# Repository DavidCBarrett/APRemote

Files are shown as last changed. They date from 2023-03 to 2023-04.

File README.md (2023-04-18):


# APRemote
Web based autopilot control using ESP32 and Seatalk1

Seatalk 1 is a 9bit protocol with 9th bit being set to indicate a command byte. Decoding is done using the ESPSoftwareSerial library.
INitialise the software port as 8 bit and Space parity. Test the parity bit before reading data if it is set then the byte
being read is a command bit.

ESP32 sketch on Arduino IDE. Reads and writes Seatalk1 to display data and send AP commannds to control X10 smart pilot.

Seatalk processing in Core 0 on ESP32.

HTML/CSS files for web page uploaded via SPIFFS.

More details to follow.

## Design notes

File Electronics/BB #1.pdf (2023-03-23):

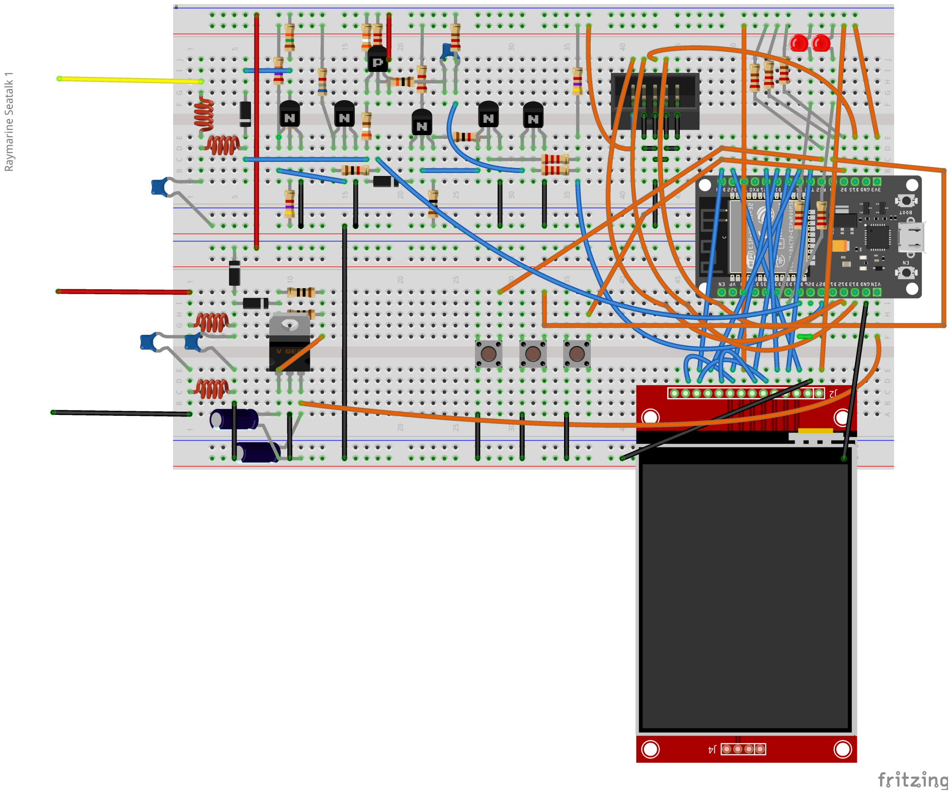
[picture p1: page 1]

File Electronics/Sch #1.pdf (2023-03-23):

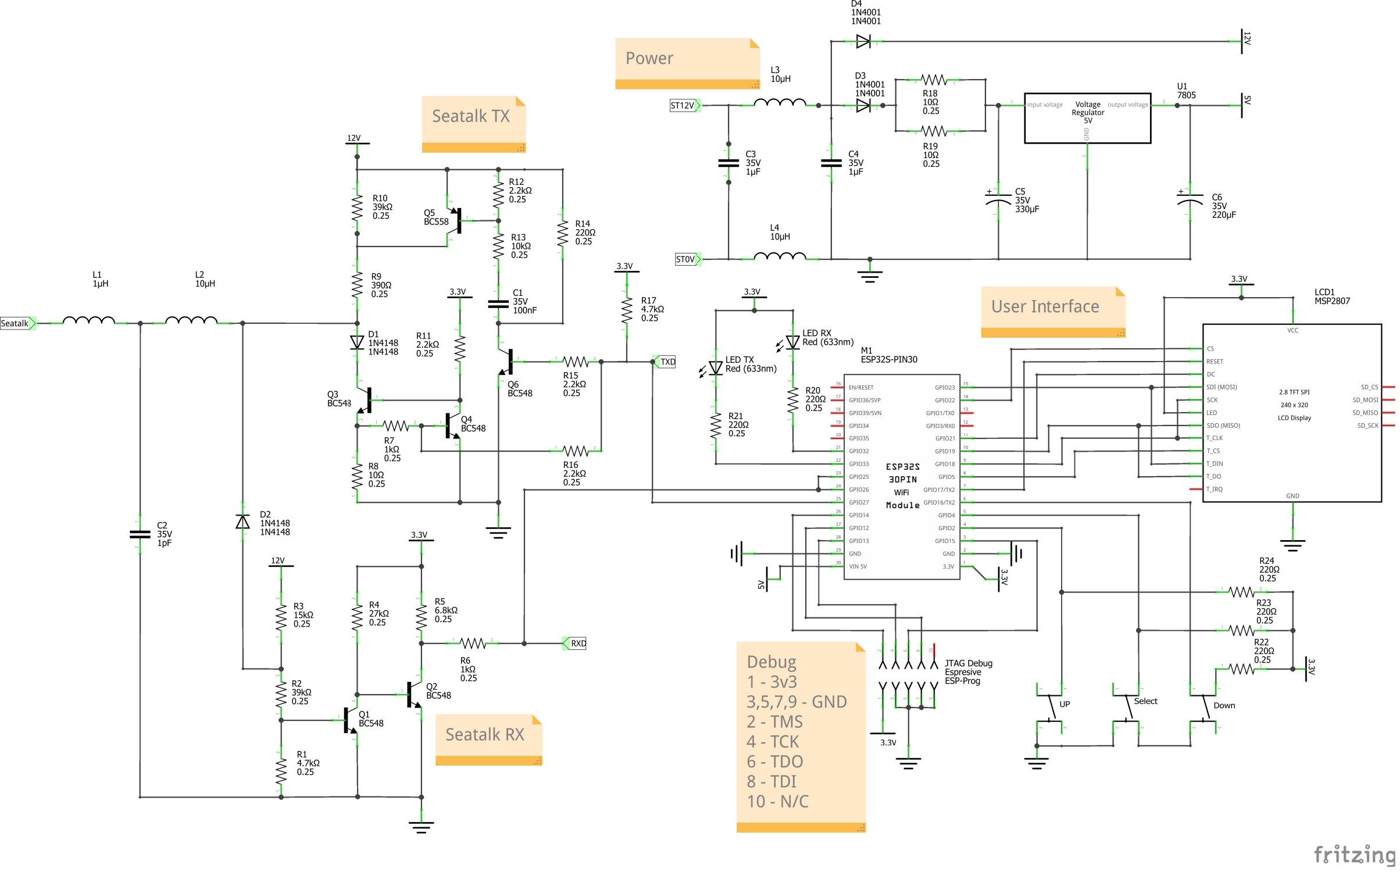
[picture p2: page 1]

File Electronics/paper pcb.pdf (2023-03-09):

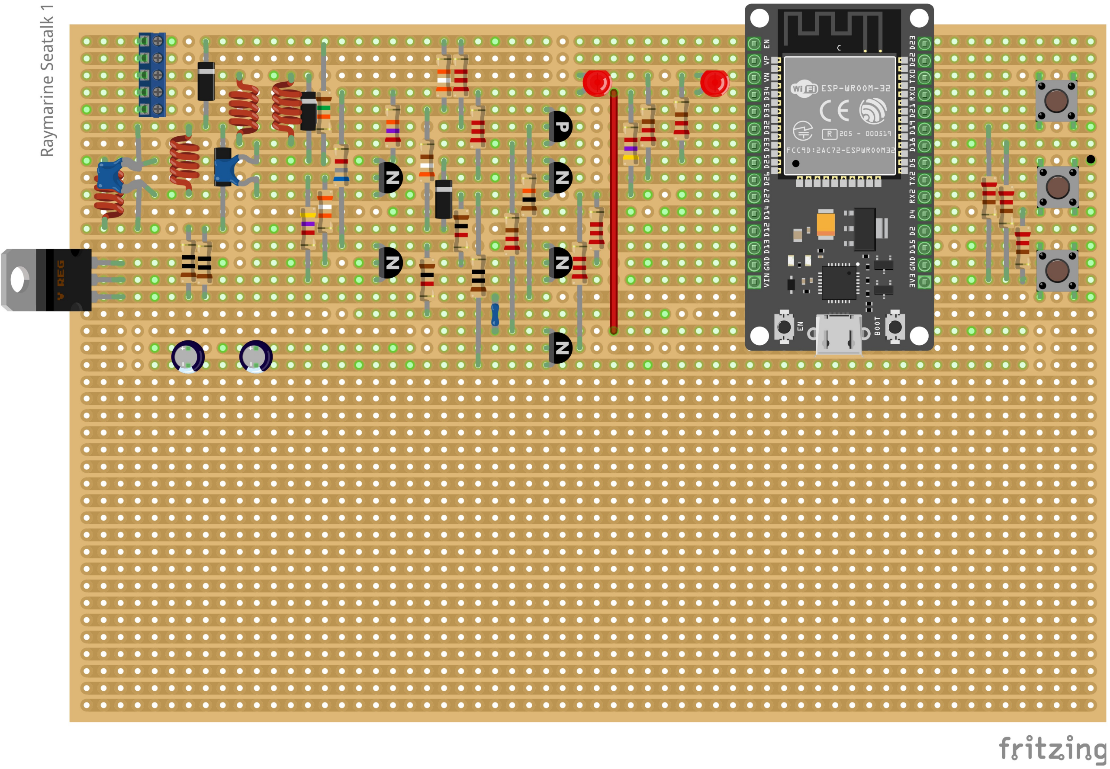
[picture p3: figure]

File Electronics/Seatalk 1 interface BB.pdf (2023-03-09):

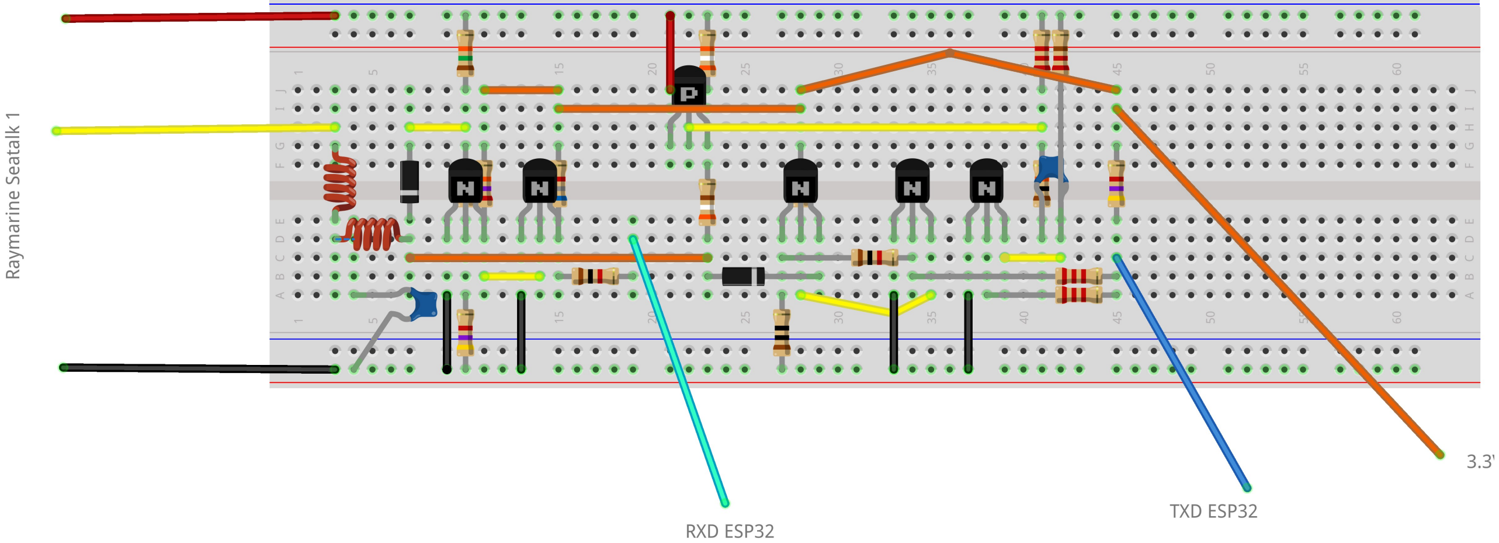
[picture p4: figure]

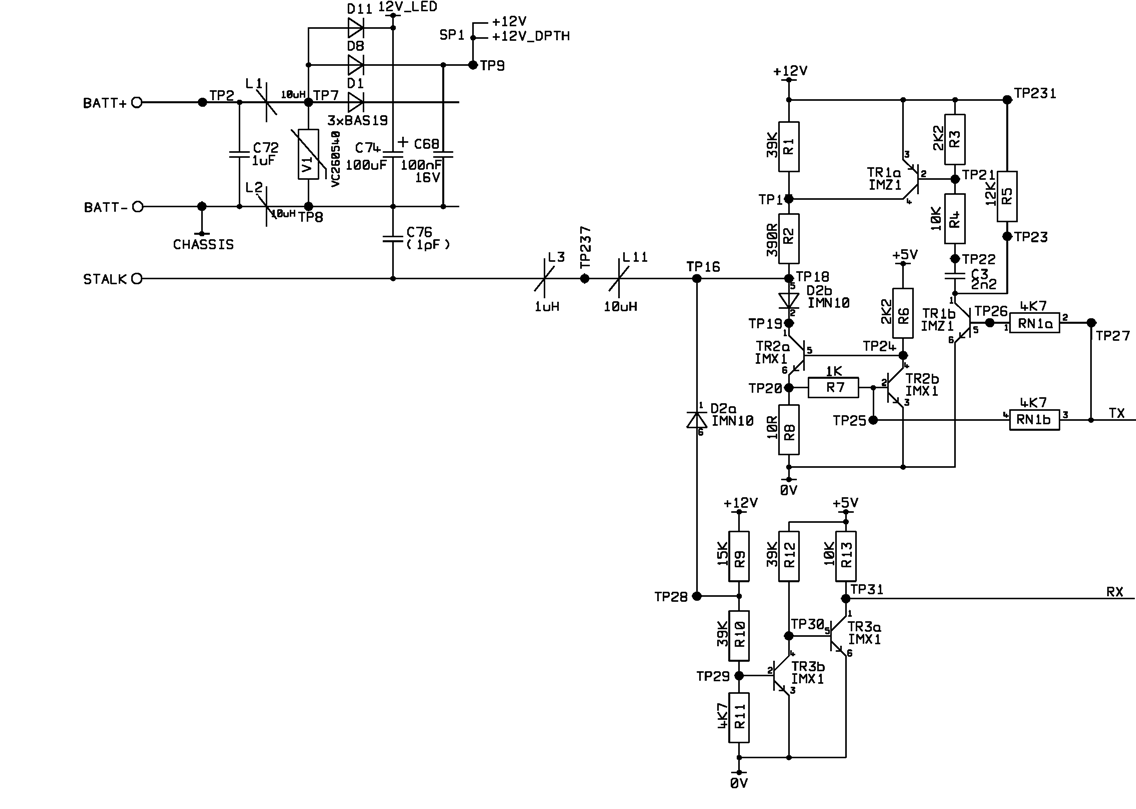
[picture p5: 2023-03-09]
Electronics/ST-IO.png

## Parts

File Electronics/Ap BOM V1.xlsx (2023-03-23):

Shopping List
Amount | MN (manufacturer number) | MPN (manufacturer part number) | Part Type | Properties
1 |  |  | Ceramic Capacitor | package 100 mil [THT, multilayer]; capacitance 100nF; voltage 35V
1 |  |  | Ceramic Capacitor | package 100 mil [THT, multilayer]; capacitance 1pF; voltage 35V
2 |  |  | Ceramic Capacitor | package 100 mil [THT, multilayer]; capacitance 1µF; voltage 35V
1 |  |  | Electrolytic Capacitor | package 100 mil [THT, electrolytic]; capacitance 330µF; voltage 35V
1 |  |  | Electrolytic Capacitor | package 100 mil [THT, electrolytic]; capacitance 220µF; voltage 35V
2 |  | 1N4148 | Rectifier Diode | package 300 mil [THT]; type Rectifier; mpn 1N4148; part # 1N4148
2 |  | 1N4001 | Rectifier Diode | package 300 mil [THT]; type Rectifier; mpn 1N4001; part # 1N4001
1 |  |  | Inductor | inductance 1µH; package 400 mil [THT]
3 |  |  | Inductor | inductance 10µH; package 400 mil [THT]
2 |  |  | Red (633nm) LED | color Red (633nm); package 3 mm [THT] Top; leg yes
1 |  |  | DOIT Esp32 DevKit v1 (30 pins long, 11 pins width) | pins 30; variant 1; part # ESP32S-PIN30
5 |  | BC548 | NPN-Transistor | package TO92 [THT]; type NPN (CBE); mpn BC548
1 |  | BC558 | PNP-Transistor | package TO92 [THT]; type PNP (CBE); mpn BC558
2 |  |  | 4.7kΩ Resistor | pin spacing 400 mil; package THT; resistance 4.7kΩ; power 0.25; bands 4; tolerance ±5%
2 |  |  | 39kΩ Resistor | pin spacing 400 mil; package THT; resistance 39kΩ; power 0.25; bands 4; tolerance ±5%
1 |  |  | 15kΩ Resistor | pin spacing 400 mil; package THT; resistance 15kΩ; power 0.25; bands 4; tolerance ±5%
1 |  |  | 27kΩ Resistor | pin spacing 400 mil; package THT; resistance 27kΩ; power 0.25; bands 4; tolerance ±5%
1 |  |  | 6.8kΩ Resistor | pin spacing 400 mil; package THT; resistance 6.8kΩ; power 0.25; bands 4; tolerance ±5%
2 |  |  | 1kΩ Resistor | pin spacing 400 mil; package THT; resistance 1kΩ; power 0.25; bands 4; tolerance ±5%
3 |  |  | 10Ω Resistor | pin spacing 400 mil; package THT; resistance 10Ω; power 0.25; bands 4; tolerance ±5%
1 |  |  | 390Ω Resistor | pin spacing 400 mil; package THT; resistance 390Ω; power 0.25; bands 4; tolerance ±5%
4 |  |  | 2.2kΩ Resistor | pin spacing 400 mil; package THT; resistance 2.2kΩ; power 0.25; bands 4; tolerance ±5%
1 |  |  | 10kΩ Resistor | pin spacing 400 mil; package THT; resistance 10kΩ; power 0.25; bands 4; tolerance ±5%
6 |  |  | 220Ω Resistor | pin spacing 400 mil; package THT; resistance 220Ω; power 0.25; bands 4; tolerance ±5%
3 |  |  | Pushbutton | package [THT]; switch status Released
1 |  | 7805 | Voltage Regulator - 5V | package TO220 [THT]; voltage 5V; mpn 7805

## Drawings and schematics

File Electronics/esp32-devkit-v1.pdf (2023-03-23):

MICRO USB | VOLTAGE REGULATOR

# BOOT & ENABLE

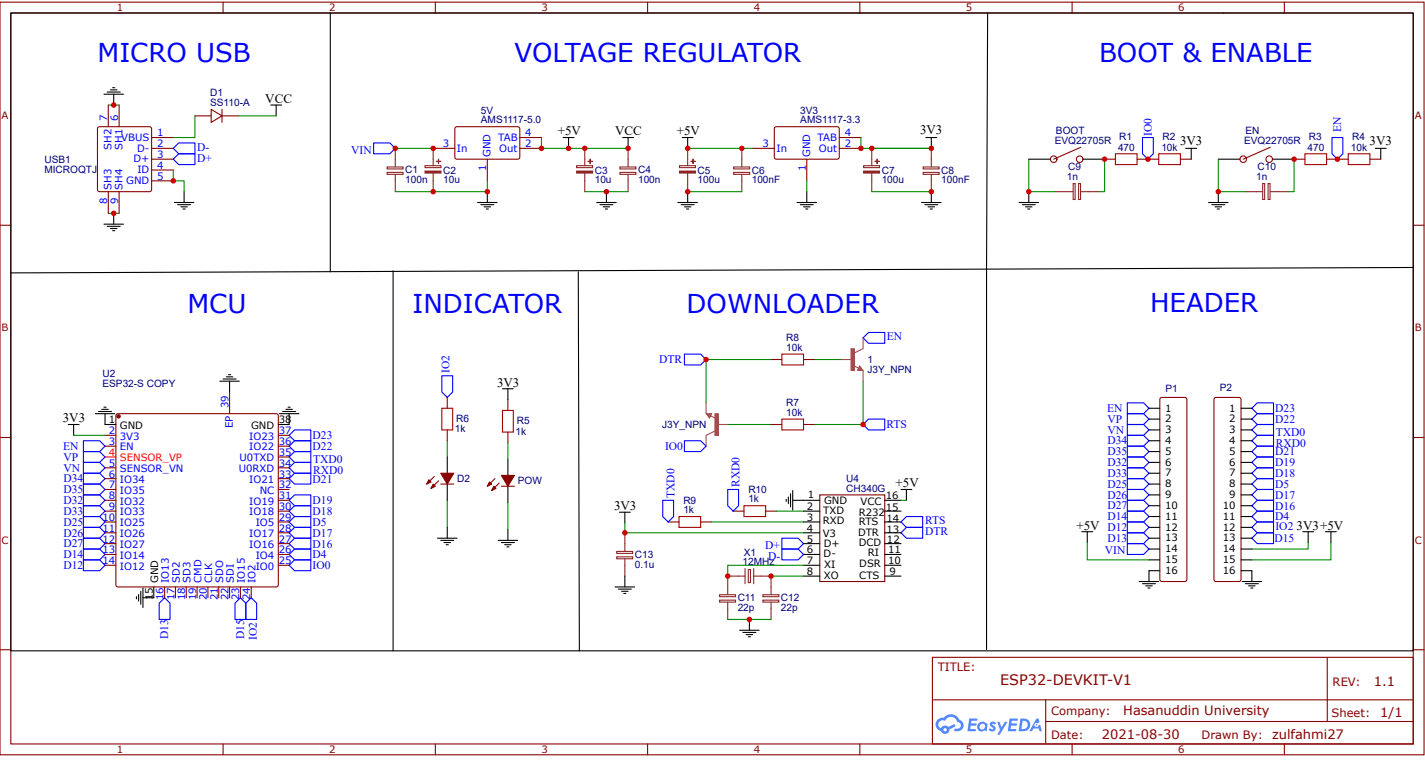
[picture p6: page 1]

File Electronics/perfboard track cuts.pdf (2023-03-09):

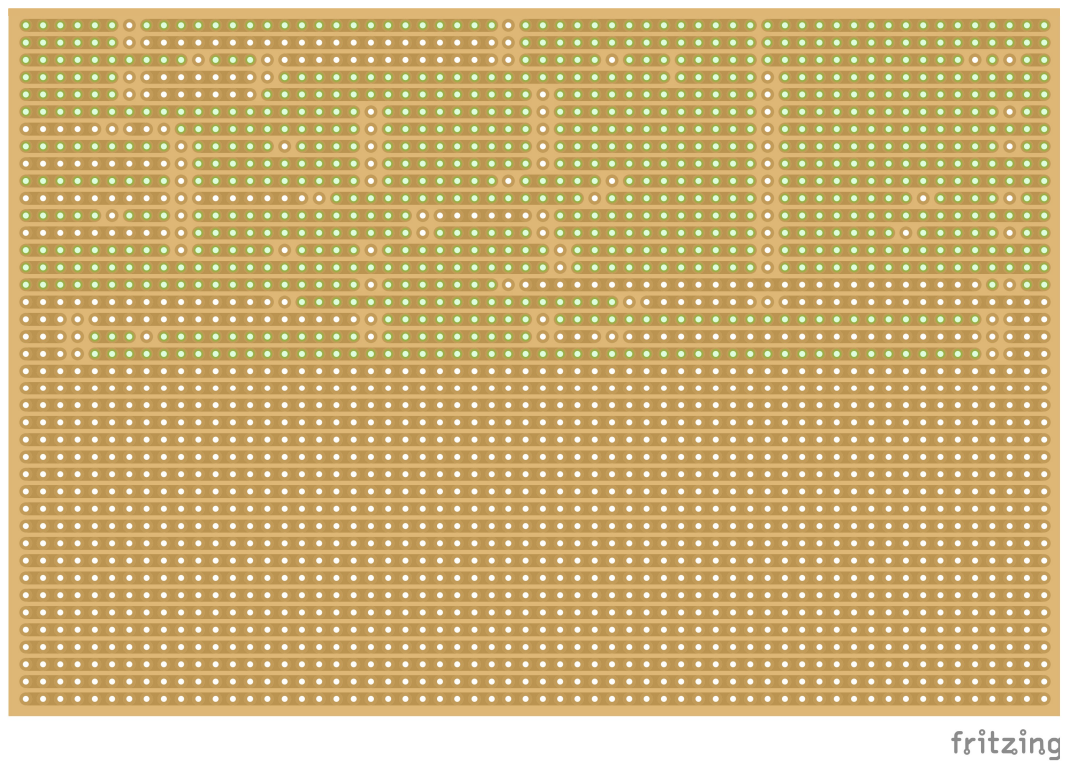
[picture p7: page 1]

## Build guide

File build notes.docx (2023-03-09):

ApRemote – a web based Raymarine SeaTalk 1 autohelm remote control

Source: https://github.com/richardJG/APRemote, Last commit, Nov 2020

Platform IO

Libraries for build:

Name & author | PlatformIO libdeps entry: | Version | Maintainer

Moving to alternative web sockets library & code in ApRemote in PlatformIO

https://m1cr0lab-esp32.github.io/remote-control-with-websocket/led-setup/

Now complies :-)

String send to client with data is:

267{"hdg":0,"cts":0,"hdgInfo":"&nbsp;","rsa":"S0","sog":0.00,"cog":0,"awa":"0S","xte":"---","aws":0.00,"vlw":0.00,"dpt":0.00,"stw":0.00,"dtw":"---","btw":"---","left":"&nbsp;","right":"&nbsp;","led0":"led_on","led1":"led_off","led2":"led_off","led3":"led_off","alm":" "}

Adding Wi-Fi Access point capability

Rui Santo’s Tutorials: https://RandomNerdTutorials.com/

ESP32 Access Point (AP) for Web Server | Random Nerd Tutorials (https://randomnerdtutorials.com/esp32-access-point-ap-web-server/)

SeaTalk 1 interface circuit.

Original (for 5V microcontroller):


Reworked for 3.3V microcontroller:

Using EasyEDA simulation mode.

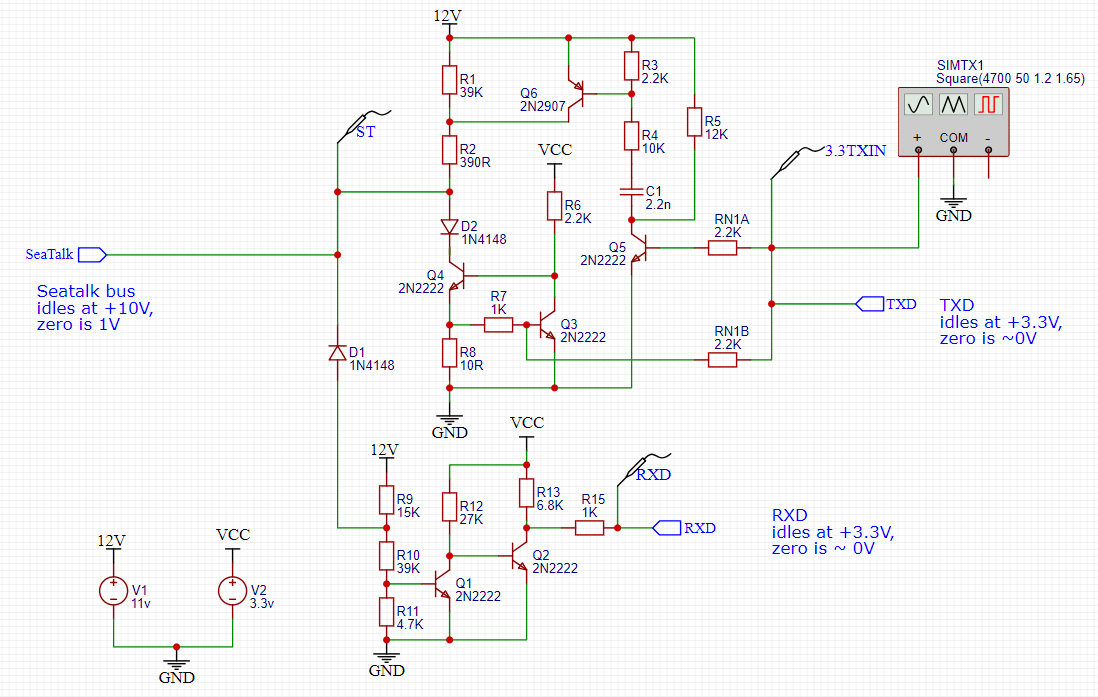
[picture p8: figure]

5V (VCC) related resistors have been scaled by 3.3/5 and nearest standard value selected.

Simulation showed circuit works with 11, 12 and 14V charge states of 12V lead acid battery.

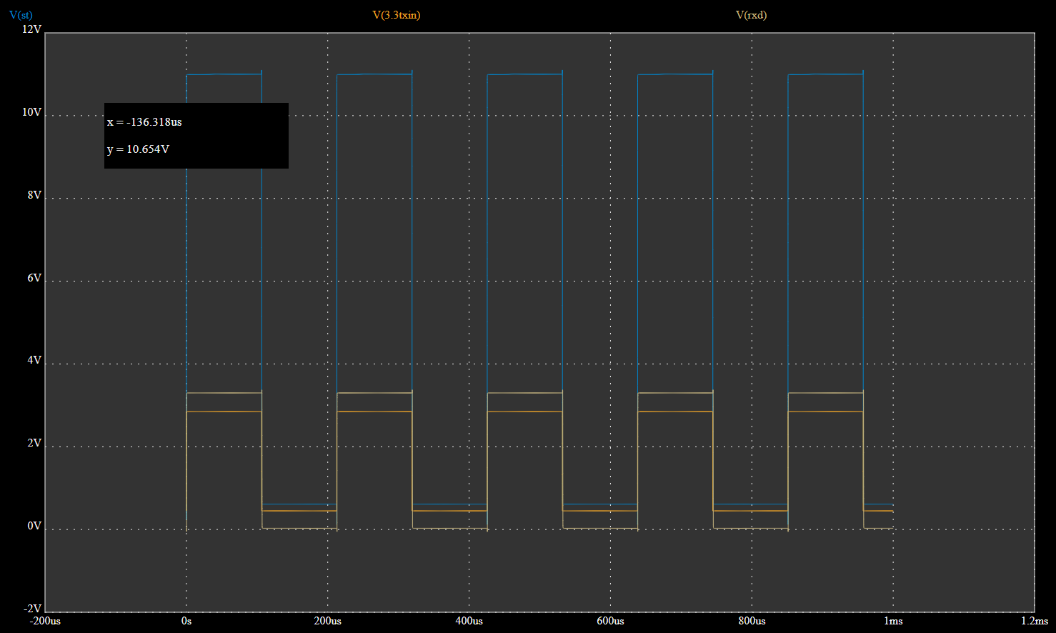
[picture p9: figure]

Prototyping the circuit

Veroboard layout tool: https://github.com/bancika/diy-layout-creator

Tutorial: https://www.youtube.com/watch?v=mzje3eHqi2E

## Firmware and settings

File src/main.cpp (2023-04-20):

//<App !Start!>
// FILE: [main.cpp]
// Created by GUIslice Builder version: [0.17.b21]
//
// GUIslice Builder Generated File
//
// For the latest guides, updates and support view:
// https://github.com/ImpulseAdventure/GUIslice
//
//<App !End!>

/*
WebServer for Raymarine Seatalk 1 based autohelm (with other boat data). 
Control your autohelm & see boat data using your phone's web browser.

Original project from https://github.com/richardJG/APRemote 

Main changes: 
1. Migrated to VS Code with PlatformIO enviornment

2. Swapped out WebSockets_Generic (which caused me lots of comple problems) for the Web Socket Server already in ESPAsyncWebServer. 
   Inpiration / info for the changes taken from the tutorial at https://m1cr0lab-esp32.github.io/remote-control-with-websocket/

3. Moved from hard coded WiFI credentials to using WiFiManager with AutoPilot Remote Access Point Web page at 192.168.4.1. 
   Connecting to the AutoPilot Remote network will bring up the web page.

4. Added buttons to ESP32. use is up/sel/down for (future) menu items, or to start a wifimanager connect session...
   using "PinButton" (AKA poelstra/MultiButton & poelstra/arduino-multi-button) library from 
   https://github.com/poelstra/arduino-multi-button/?utm_source=platformio&utm_medium=piohome

5. Added heartbeat LED using HeartBeat library by Rob Tillaart 
   https://github.com/RobTillaart/HeartBeat?utm_source=platformio&utm_medium=piohome
   Using the onboard LED (GPIO 2). 

6. Added "ILI9341 SPI TFT with XPT2046 SPI touch screen" to act as an alternative AP remote UI device, when phone or wifi isnt working
   Library is Bodmer/TFT_eSPI at https://github.com/Bodmer/TFT_eSPI?utm_source=platformio&utm_medium=piohome

7. Using phone as a webclient, when the phone autolocks, it drops the websocket connection & had to refresh the page to get connection back. 
   In the client' Javascript, changed from WebSocket to ReconnectingWebSocket to give auto-reconnect on unlock.
       Reconnecting websockets javascript: https://github.com/joewalnes/reconnecting-websocket; 
       Reconnecting websocketsexample: https://mpolinowski.github.io/docs/Development/Javascript/2021-09-10--websocket-recconects/2021-09-10/
   Had to change webserver setup code to include "server.serveStatic("/", SPIFFS, "/");". I beleive this serves all files requested by the 
   client from the SPIFF file system.

8. Browser's inspector was grumbling "favicon.ico" was missing. Favicon files created using https://favicon.io/favicon-generator/ and added to data directory. 
   Link tags added to HTML head as suggested on above page.

libraries used at Mar 20223 were:
	plerup/EspSoftwareSerial@7.0.0
  esphome/AsyncTCP-esphome@^1.2.2
  esphome/ESPAsyncWebServer-esphome@^2.1.0
  alanswx/ESPAsyncWifiManager
  poelstra/MultiButton@^1.2.0
  robtillaart/HeartBeat@^0.3.2
  bodmer/TFT_eSPI@^2.5.23

TODO'S:

 1. Need to add WiFi reconnection code from here: https://github.com/alanswx/ESPAsyncWiFiManager/issues/92

 2. Finish TFT touch screen alternative UI.

 3. esp32 only works (connects to wifi) when there is an active serial monitor connected in platformio. work out why and fix.

 4. Move to a GUIslice type project, for easier TFT UI updates.

*/

// ------------------------------------------------
// Headers to include
// ------------------------------------------------
#include <Arduino.h>
#include <PinButton.h>
#include <HeartBeat.h>

#include "main.h"
#include "ApEsp32Pins.h"
#include "ApWifi.h"
#include "DCBWiFiManager.h"
#include "SeaTalk.h"
#include "ApRemote_GSLC.h"
#include "GSLC_Helpers.h"

// ------------------------------------------------
// Program Globals
// ------------------------------------------------

//create button objects
// PinButton btnUp(BTN_UP);
PinButton btnDown(BTN_DOWN);
PinButton btnSelect(BTN_SELECT);

// Heartbeat object for onboard LED 
HeartBeatDiag HB;
HeartBeatDiag TXHB;
HeartBeatDiag RXHB;

// Save some element references for direct access
//<Save_References !Start!>
gslc_tsElemRef* m_pElemBrnBaseWiFi= NULL;
gslc_tsElemRef* m_pElemBtnAprAuto = NULL;
gslc_tsElemRef* m_pElemBtnAprMinusOne= NULL;
gslc_tsElemRef* m_pElemBtnAprMinusTen= NULL;
gslc_tsElemRef* m_pElemBtnAprPlusOne= NULL;
gslc_tsElemRef* m_pElemBtnAprPlusTen= NULL;
gslc_tsElemRef* m_pElemBtnAprPortTack= NULL;
gslc_tsElemRef* m_pElemBtnAprStandby= NULL;
gslc_tsElemRef* m_pElemBtnAprStbdTack= NULL;
gslc_tsElemRef* m_pElemBtnAprTrack= NULL;
gslc_tsElemRef* m_pElemBtnAprWind = NULL;
gslc_tsElemRef* m_pElemBtnBaseApr = NULL;
gslc_tsElemRef* m_pElemBtnBaseData= NULL;
gslc_tsElemRef* m_pElemBtnBaseDiag= NULL;
gslc_tsElemRef* m_pElemBtnDiagClear= NULL;
gslc_tsElemRef* m_pElemBtnDiagPause= NULL;
gslc_tsElemRef* m_pElemBtnDiagPlay= NULL;
gslc_tsElemRef* m_pElemBtnWiFiClear= NULL;
gslc_tsElemRef* m_pElemBtnWiFiPause= NULL;
gslc_tsElemRef* m_pElemBtnWifiConnect= NULL;
gslc_tsElemRef* m_pElemBtnWifiDisconnect= NULL;
gslc_tsElemRef* m_pElemBtnWifiPlay= NULL;
gslc_tsElemRef* m_pElemBtnWifiReset= NULL;
gslc_tsElemRef* m_pElemDiagStatus = NULL;
gslc_tsElemRef* m_pElemRadioButtonAprAuto= NULL;
gslc_tsElemRef* m_pElemRadioButtonAprStandby= NULL;
gslc_tsElemRef* m_pElemRadioButtonAprTrack= NULL;
gslc_tsElemRef* m_pElemRadioButtonAprWind= NULL;
gslc_tsElemRef* m_pElemTextAprDisplay= NULL;
gslc_tsElemRef* m_pElemTextDataDepth= NULL;
gslc_tsElemRef* m_pElemTextDataHdg= NULL;
gslc_tsElemRef* m_pElemTextDataSog= NULL;
gslc_tsElemRef* m_pElemTextDataSow= NULL;
gslc_tsElemRef* m_pElemTextDataWDir= NULL;
gslc_tsElemRef* m_pElemTextDataWind= NULL;
gslc_tsElemRef* m_pElemTextWifiClientSSID= NULL;
gslc_tsElemRef* m_pElemTextWifiIp = NULL;
gslc_tsElemRef* m_pElemTextWifiSSID= NULL;
gslc_tsElemRef* m_pElemTextWifiStatus= NULL;
gslc_tsElemRef* m_pElemTextboxDiagLog= NULL;
gslc_tsElemRef* m_pElemTextboxWiFiDiag= NULL;
gslc_tsElemRef* m_pElemTxtBaseWiFiStrength= NULL;
gslc_tsElemRef* m_pTextSliderDiagLog= NULL;
gslc_tsElemRef* m_pTextSliderWifiDiag= NULL;
//<Save_References !End!>

// Define debug message function
static int16_t DebugOut(char ch) { if (ch == (char)'\n') Serial.println(""); else Serial.write(ch); return 0; }


// BASE Page
GSLC_Txt_Helper txtBaseWiFiStrength(&m_gui, &m_pElemTxtBaseWiFiStrength);

// DIAG Page
GSLC_TextBox_Helper txtDiagLog(&m_gui, &m_pElemTextboxDiagLog);
GSLC_Txt_Helper txtDiagStatus(&m_gui, &m_pElemDiagStatus);

// WiFi Page
GSLC_Txt_Helper txtWiFiStatus(&m_gui, &m_pElemTextWifiStatus);
GSLC_Txt_Helper txtWiFiSSID(&m_gui, &m_pElemTextWifiSSID);
GSLC_Txt_Helper txtWiFiIp(&m_gui, &m_pElemTextWifiIp);
GSLC_Txt_Helper txtWiFiClient(&m_gui, &m_pElemTextWifiClientSSID);
GSLC_TextBox_Helper txtWiFiDiag(&m_gui, &m_pElemTextboxWiFiDiag);

// APR Page
GSLC_Txt_Helper txtAprDisplay(&m_gui, &m_pElemTextAprDisplay);


// Data Page
GSLC_Txt_Helper txtDataSog(&m_gui, &m_pElemTextDataSog);
GSLC_Txt_Helper txtDataSow(&m_gui, &m_pElemTextDataSow);
GSLC_Txt_Helper txtDataWind(&m_gui, &m_pElemTextDataWind);
GSLC_Txt_Helper txtDataWDir(&m_gui, &m_pElemTextDataWDir);
GSLC_Txt_Helper txtDataHdg(&m_gui, &m_pElemTextDataHdg);
GSLC_Txt_Helper txtDataDepth(&m_gui, &m_pElemTextDataDepth);

// ------------------------------------------------
// Callback Methods
// ------------------------------------------------
// Common Button callback
bool CbBtnCommon(void* pvGui,void *pvElemRef,gslc_teTouch eTouch,int16_t nX,int16_t nY)
{
  // Typecast the parameters to match the GUI and element types
  gslc_tsGui*     pGui     = (gslc_tsGui*)(pvGui);
  gslc_tsElemRef* pElemRef = (gslc_tsElemRef*)(pvElemRef);
  gslc_tsElem*    pElem    = gslc_GetElemFromRef(pGui,pElemRef);

  if ( eTouch == GSLC_TOUCH_UP_IN ) {
    // From the element's ID we can determine which button was pressed.
    switch (pElem->nId) {
//<Button Enums !Start!>
      case E_ELEM_BTN_BASE_DIAG:
        gslc_SetPageCur(&m_gui, E_PG_DIAG);
        break;
      case E_ELEM_BTN_BASE_APR:
        gslc_SetPageCur(&m_gui, E_PG_APR);
        break;
      case E_ELEM_BTN_BASE_WIFI:
        gslc_SetPageCur(&m_gui, E_PG_WIFI);
        break;
      case E_ELEM_BTN_BASE_DATA:
        gslc_SetPageCur(&m_gui, E_PG_DATA);
        break;
      case E_ELEM_BTN_DIAG_PLAY:
        txtDiagLog.setTextOutStatus(GSLC_TextBox_Helper::TxtOutStatusEnum::TxtOutPlay);
        break;
      case E_ELEM_BTN_DIAG_PAUSE:
        txtDiagLog.setTextOutStatus(GSLC_TextBox_Helper::TxtOutStatusEnum::TxtOutPaused);
        break;
      case E_ELEM_BTN_DIAG_CLEAR:
        txtDiagLog.clear();
        break;
      case E_ELEM_BTN_APR_STDBY:
        txtDiagLog.printf("TFT Standby\n");
        break;
      case E_ELEM_BTN_APR_AUTO:
        txtDiagLog.printf("TFT Auto\n");
        break;
      case E_ELEM_BTN_APR_WIND:
        txtDiagLog.printf("TFT Wind\n");
        break;
      case E_ELEM_BTN_APR_TRACK:
        txtDiagLog.printf("TFT Track\n");
        break;
      case E_ELEM_BTN_APR_PLUS_ONE:
        break;
      case E_ELEM_BTN_APR_PLUS_TEN:
        break;
      case E_ELEM_BTN_APR_STBD_TACK:
        break;
      case E_ELEM_BTN_APR_MINUS_ONE:
        break;
      case E_ELEM_BTN_APR_MINUS_TEN:
        break;
      case E_ELEM_BTN_APR_PORT_TACK:
        break;
      case E_ELEM_BTN_WIFI_CONNECT:
        wm.OnUserConnectRequest();
        break;
      case E_ELEM_BTN_WIFI_RESET:
        wm.resetSettings();
        break;
      case E_ELEM_BTN_WIFI_DISCONNECT:
        wm.OnUserDisconnectRequest();
        break;
      case E_ELEM_BTN_WIFI_PLAY:
        txtWiFiDiag.setTextOutStatus(GSLC_TextBox_Helper::TxtOutStatusEnum::TxtOutPlay);
        break;
      case E_ELEM_BTN_WIFI_PAUSE:
        txtWiFiDiag.setTextOutStatus(GSLC_TextBox_Helper::TxtOutStatusEnum::TxtOutPaused);
        break;
      case E_ELEM_BTN_WIFI_CLEAR:
        txtWiFiDiag.clear();
        break;
//<Button Enums !End!>
      default:
        break;
    }
  }
  return true;
}
// Checkbox / radio callbacks
// - Creating a callback function is optional, but doing so enables you to
//   detect changes in the state of the elements.
bool CbCheckbox(void* pvGui, void* pvElemRef, int16_t nSelId, bool bState)
{
  gslc_tsGui*     pGui      = (gslc_tsGui*)(pvGui);
  gslc_tsElemRef* pElemRef  = (gslc_tsElemRef*)(pvElemRef);
  gslc_tsElem*    pElem     = gslc_GetElemFromRef(pGui,pElemRef);
  if (pElemRef == NULL) {
    return false;
  }
  
  boolean bChecked = gslc_ElemXCheckboxGetState(pGui,pElemRef);

  // Determine which element issued the callback
  switch (pElem->nId) {
//<Checkbox Enums !Start!>
    case E_ELEM_RADIO_APR_STANDBY:
      break;
    case E_ELEM_RADIO_APR_AUTO:
      break;
    case E_ELEM_RADIO_APR_WIND:
      break;
    case E_ELEM_RADIO_APR_TRACK:
      break;

//<Checkbox Enums !End!>
    default:
      break;
  } // switch
  return true;
}
//<Keypad Callback !Start!>
//<Keypad Callback !End!>
//<Spinner Callback !Start!>
//<Spinner Callback !End!>
//<Listbox Callback !Start!>
//<Listbox Callback !End!>
//<Draw Callback !Start!>
//<Draw Callback !End!>

// Callback function for when a slider's position has been updated
bool CbSlidePos(void* pvGui,void* pvElemRef,int16_t nPos)
{
  gslc_tsGui*     pGui     = (gslc_tsGui*)(pvGui);
  gslc_tsElemRef* pElemRef = (gslc_tsElemRef*)(pvElemRef);
  gslc_tsElem*    pElem    = gslc_GetElemFromRef(pGui,pElemRef);
  int16_t         nVal;

  // From the element's ID we can determine which slider was updated.
  switch (pElem->nId) {
//<Slider Enums !Start!>
    case E_TXTSCROLL_DIAG_LOG:
      // Fetch the slider position
      nVal = gslc_ElemXSliderGetPos(pGui,m_pTextSliderDiagLog);
      gslc_ElemXTextboxScrollSet(pGui,m_pElemTextboxDiagLog,nVal,100);  // DCB: use slider position to set text box scroll posn
      break;

    case E_TXTSCROLL_WIFI_DIAG:
      // Fetch the slider position
      nVal = gslc_ElemXSliderGetPos(pGui,m_pTextSliderWifiDiag);
      gslc_ElemXTextboxScrollSet(pGui,m_pElemTextboxWiFiDiag,nVal,100);  // DCB: use slider position to set text box scroll posn
      break;
//<Slider Enums !End!>
    default:
      break;
  }

  return true;
}
//<Tick Callback !Start!>
//<Tick Callback !End!>

void ApGslc_Update() {
  gslc_Update(&m_gui);  
}

void setup()
{
  Serial.begin(115200);
  while(!Serial) delay(100);
  delay(500);

  Serial.printf("----------------------\n-- Sea Talk Web Remote\n----------------------\n");

  // ------------------------------------------------
  // Initialize
  // ------------------------------------------------
  pinMode(RX_MON, INPUT);
  pinMode(RX_LED, OUTPUT_OPEN_DRAIN);
  pinMode(TX_LED, OUTPUT_OPEN_DRAIN);

  HB.begin(LED_PIN, 1);  // PIN ID and frequency 3
  HB.setDutyCycle(17.53);
 
  TXHB.begin(TX_LED, 1);
  RXHB.begin(RX_LED, 1);

  // ------------------------------------------------
  // Create graphic elements
  // ------------------------------------------------
  gslc_InitDebug(&DebugOut);
  InitGUIslice_gen();

  txtDiagLog.printf("----------------------\n-- Sea Talk Web Remote\n----------------------\n");
  gslc_Update(&m_gui);

  ApWiFi_Setup();

  txtDiagLog.printf("ApWiFi_Init() done \n");
  gslc_Update(&m_gui);

  Seatalk_Init();

  txtDiagLog.printf("Setup Done.\n");
  
  // Insert some text
  txtDiagLog.printf("Welcome\n");
  txtDiagLog.printf("Hi ");
  txtDiagLog.printf("Long line here that may wrap or may not that is the purpose of this test\n");
  txtDiagLog.printf("End...\n");
}

// Free-running counter for display
unsigned int m_nCount = 0;

// -----------------------------------
// Main event loop
// -----------------------------------
void loop()
{
  char cDisp[MAX_STR];

  HB.beat();
  TXHB.beat();
  RXHB.beat();
  
  // do loop mainenance / updates
  // btnUp.update();
  btnDown.update();
  btnSelect.update();

  APWiFi_Loop();

  // ------------------------------------------------
  // Update GUI Elements - Update code for any text, gauges, or sliders
  // ------------------------------------------------
  
  // Display WiFi Signal Strength or if not applicable, WiFi mode information.
  switch (WiFi.getMode()) 
  {
    case WIFI_MODE_NULL:
      txtBaseWiFiStrength.printf("NULL");
      break;
    case WIFI_MODE_STA:
      // For RSSI db to 0-100% conversion see https://stackoverflow.com/questions/15797920/how-to-convert-wifi-signal-strength-from-quality-percent-to-rssi-dbm
      // Added the /20*20 bit to reduce the resolution to steps of 20 to avoid the reported number "flickering".
      txtBaseWiFiStrength.printf("%d", (std::min(std::max(2 * (WiFi.RSSI() + 100), 0), 100) /20)*20);
      break;
    case WIFI_MODE_AP:
      txtBaseWiFiStrength.printf("AP");
      break;
    case WIFI_MODE_APSTA:
      txtBaseWiFiStrength.printf("APSTA");
      break;
    case WIFI_MODE_MAX:
      txtBaseWiFiStrength.printf("MAX");
      break;
  }

  // Data page items.

  txtAprDisplay.printf("%d Mag", hdg);

  float Randomness = random(0,360);

  sog = Randomness / 60;
  stw = Randomness * 1.5 / 60;
  aws = Randomness * 3 / 60;
  awa = (int)Randomness;
  dpt = Randomness /12;

  txtDataSog.printf("%.1f", sog);
  txtDataSow.printf("%.1f", stw);
  txtDataWind.printf("%.1f", aws);
  txtDataWDir.printf("%d Mag", awa);
  txtDataDepth.printf("%.1f", dpt);

  //if ((m_nCount++ % 5) == 0) txtWiFiDiag.printf("Step %d\n",m_nCount);

  // Slider / Scroll bar updates
  // Adjust the range of the slider based on how full the char buffer attached to the relevan text box is 
  // just for the WiFi Diag text box for now...

  // gslc_tsElemRef* pElemRef  = (gslc_tsElemRef*)(m_pElemTextboxDiagLog);
  // gslc_tsElem*    pElem     = gslc_GetElemFromRef(&m_gui,pElemRef);
  // // Fetch the element's extended data structure
  // gslc_tsXTextbox* pBox;
  // pBox = (gslc_tsXTextbox*)(pElem->pXData);

  // txtDiagLog.printf("BY= %u\n", pBox->nBufPosY);
  // txtDiagStatus.printf("WRS= %u, SP= %u\n", pBox->nWndRowStart, pBox->nScrollPos);

  // ------------------------------------------------
  // Periodically call GUIslice update function
  // ------------------------------------------------
  gslc_Update(&m_gui);
  
  delay (200);
}

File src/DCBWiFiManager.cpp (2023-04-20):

/*********
  Rui Santos
  Complete instructions at https://RandomNerdTutorials.com/esp32-wi-fi-manager-asyncwebserver/
  
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
Main Changes - make this simple wifi manager non-blocking and integrated into main application's loop & code. 
The main app should happily work with:
  a. the ESP32 as the access point - in APMode (i.e. when there is no station about cause you're on the boat), 
  b. or if the user has configured an SSID & Pwd that connect, the main app works in station mode  - in STAMode 

To do the above, moving WiFi Manager to be based on a statemachine. See here https://www.codeproject.com/Articles/1087619/State-Machine-Design-in-Cplusplus-2 
States are:
  ST_APMODE                         in this state, nothing to do but service any wifi objects
  ST_CONNECTINGTOSTA                in this state, try and connect to STA with supplied ssid & pwd, if succeed, fail, or timeout then transition.
  ST_STAMODE                        in this state, nothing to do but service any wifi objects

initial state: 
  is ST_CONNECTINGTOSTA             after power on.

state transitions:
  ST_CONNECTINGTOSTA -> ST_STAMODE  due to succesfull connection to the speciifed station.
  ST_CONNECTINGTOSTA -> ST_APMODE   due to failing to connect to specified station, maybe a timeout, or max retries
  ST_APMODE  -> ST_CONNECTINGTOSTA  due to "OnUserConnectRequest" (typically after they have configured a stations ssid & pwd)
  ST_STAMODE -> ST_CONNECTINGTOSTA  due to Wifi randomly disconnects (e.g. signal drop out) This starts ESP32 to Station reconnection attempt(s).
  ST_STAMODE -> ST_APMODE           due to "OnUserDisconnectRequest"

External events:
  OnUserConnectRequest          Move from AP to STA mode, and try and connect with saved ssid and pwd
  OnUserDisconnectRequest       disconnect from any station, enter APMode.

Using Timoutout libaray from https://github.com/tfeldmann/Arduino-Timeout

*********/
#include "DCBWiFiManager.h"

#include <Arduino.h>
#include <WiFi.h>
#include <AsyncTCP.h>
#include <SPIFFS.h>

#include "main.h"
#include "GSLC_Helpers.h"

#define DNS_PORT      53

DCBWiFiManager::DCBWiFiManager(AsyncWebServer* server, const char* APSSID) : StateMachine(ST_MAX_STATES) {

  _apssid = APSSID;
  _server = server;
  
  if (SPIFFS.begin(true)) {
    // Load values saved in SPIFFS
    _ssid   = readFile(SPIFFS, ssidPath);
    _pass   = readFile(SPIFFS, passPath);
    ip      = readFile(SPIFFS, ipPath);
    gateway = readFile(SPIFFS, gatewayPath);

    Serial.printf("From SPIFFS - SSID:%s, PWD: %s, IP: %s, Gateway: %s\n ", _ssid, _pass, ip.c_str(), gateway.c_str());
  }
  else {
    Serial.println("DCBWiFiManager::DCBWiFiManager An error has occurred while mounting SPIFFS");
  }

  // Web Server setup. Root URL belongs to the application. the wifimanager.html page is a website page served up 
  // by "serveStatic("/", SPIFFS, "/")"" set up the applicaiton.

  // Handle the posts that happen when the user updates the fields on the wifimanager.html page.
  _server->on("/", HTTP_POST, [this](AsyncWebServerRequest *request) {
    int params = request->params();
    for(int i=0;i<params;i++){
      AsyncWebParameter* p = request->getParam(i);
      if(p->isPost()){
        // HTTP POST ssid value
        if (p->name() == PARAM_INPUT_1) {
          _ssid = p->value().c_str();
          Serial.print("SSID set to: ");
          Serial.println(_ssid);
          // Write file to save value
          writeFile(SPIFFS, ssidPath, _ssid.c_str());
        }
        // HTTP POST _pass value
        if (p->name() == PARAM_INPUT_2) {
          _pass = p->value().c_str();
          Serial.print("Password set to: ");
          Serial.println(_pass);
          // Write file to save value
          writeFile(SPIFFS, passPath, _pass.c_str());
        }
        // HTTP POST ip value
        if (p->name() == PARAM_INPUT_3) {
          ip = p->value().c_str();
          Serial.print("IP Address set to: ");
          Serial.println(ip);
          // Write file to save value
          writeFile(SPIFFS, ipPath, ip.c_str());
        }
        // HTTP POST gateway value
        if (p->name() == PARAM_INPUT_4) {
          gateway = p->value().c_str();
          Serial.print("Gateway set to: ");
          Serial.println(gateway);
          // Write file to save value
          writeFile(SPIFFS, gatewayPath, gateway.c_str());
        }
        //Serial.printf("POST[%s]: %s\n", p->name().c_str(), p->value().c_str());
      }
    }
    request->send(200, "text/plain", "Done. ESP will restart, connect to your router and go to IP address: " + ip);
    delay(3000);
    ESP.restart();
  });
}

//
// external events taken by this state machine
//

void DCBWiFiManager::OnUserConnectRequest() {
   // given the OnUserConnectRequest event, transition to a new state based upon 
   // the current state of the state machine - real work is done in the ST_XXX functions
    BEGIN_TRANSITION_MAP                            // - Current State -
        TRANSITION_MAP_ENTRY (ST_CONNECTINGTOSTA)   // ST_BOOTUP
        TRANSITION_MAP_ENTRY (ST_CONNECTINGTOSTA)   // ST_APMODE
        TRANSITION_MAP_ENTRY (CANNOT_HAPPEN)        // ST_CONNECTINGTOSTA
        TRANSITION_MAP_ENTRY (CANNOT_HAPPEN)        // ST_STAMODE
    END_TRANSITION_MAP(NULL)
}

void DCBWiFiManager::OnUserDisconnectRequest() {
   // given the OnUserConnectRequest event, transition to a new state based upon 
   // the current state of the state machine - real work is done in the ST_XXX functions
    BEGIN_TRANSITION_MAP                            // - Current State -
        TRANSITION_MAP_ENTRY (CANNOT_HAPPEN)        // ST_BOOTUP
        TRANSITION_MAP_ENTRY (EVENT_IGNORED)        // ST_APMODE
        TRANSITION_MAP_ENTRY (ST_APMODE)            // ST_CONNECTINGTOSTA
        TRANSITION_MAP_ENTRY (ST_APMODE)            // ST_STAMODE
    END_TRANSITION_MAP(NULL)
}

void DCBWiFiManager::poll() {
   // hopefully this will just poll the current state, calling the relevant STATE_DEFINE function below.
    BEGIN_TRANSITION_MAP                            // - Current State -
        TRANSITION_MAP_ENTRY (ST_BOOTUP)            // ST_BOOTUP
        TRANSITION_MAP_ENTRY (ST_APMODE)            // ST_APMODE
        TRANSITION_MAP_ENTRY (ST_CONNECTINGTOSTA)   // ST_CONNECTINGTOSTA
        TRANSITION_MAP_ENTRY (ST_STAMODE)           // ST_STAMODE
    END_TRANSITION_MAP(NULL)
}

STATE_DEFINE(DCBWiFiManager,     Bootup,                  NoEventData) {
  // Nothing to do.
}
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

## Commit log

2023-02-18 Updating to compile in 2023
    Main change is dumping WebSockets_Generic as it was causing LOTS of compile issues.
    The Web Socket Server in ESPAsyncWebServer is used instead.
    [main.cpp]
2023-03-09 Added electronics< schematic, breadboard and perfboard layouts moving to ESP Wifi Manager instead of hard coded ssid etc
    [Seatalk 1 Breadboard sch-v1.fzz, Seatalk 1 Breadboard.fzz, Seatalk 1 PerfBoard sch-v1.fzz]
2023-03-23 interim build ahead of trying to make wifimanager non blocking.
    [Ap BOM V1.xlsx, Seatalk 1 Breadboard sch-v1.fzz, Seatalk 1 Breadboard.fzz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]
2023-04-05 After finding out the software doesnt freeze in wifi setup when ESP32 is powered externally
2023-04-06 added delay for wifi setup page trying to fix stuck in loop without serial terminal connected via USB...
    [main.cpp]
2023-04-11 Almost before trying to switch to tzapu's latest non blocking wifimanager
2023-04-14 corrections in WiFI screen and state machine. Wifi SIgnal strength added.
    [ApWiFi.cpp, DCBWiFiManager.cpp, main.cpp]
2023-04-17 Created GSLC_Helpers to clean up interface to parts of the TFT, and added pause/play/clear buttons to the Diag Log
2023-04-18 Add the Azure Boards badge to the README. Fixes AB#12
2023-04-20 Added captive portal for use in AP mode fixes AB#8
    [ApWiFi.cpp, DCBWiFiManager.cpp, main.cpp]
